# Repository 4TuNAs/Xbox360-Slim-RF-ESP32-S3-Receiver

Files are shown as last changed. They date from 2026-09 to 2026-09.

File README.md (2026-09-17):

# Xbox 360 Slim RF Board + ESP32-S3 SuperMini USB Receiver

A DIY Xbox 360 wireless controller receiver built around the **original Xbox 360 Slim RF board** and an **ESP32-S3 SuperMini**.

The ESP32 initializes the Microsoft RF board and handles its DATA, CLOCK, and SYNC/BTN control lines. USB data is connected to the RF board, while the ESP32-S3 is powered from USB +5 V and supplies 3.3 V to the RF board.

## Finished build

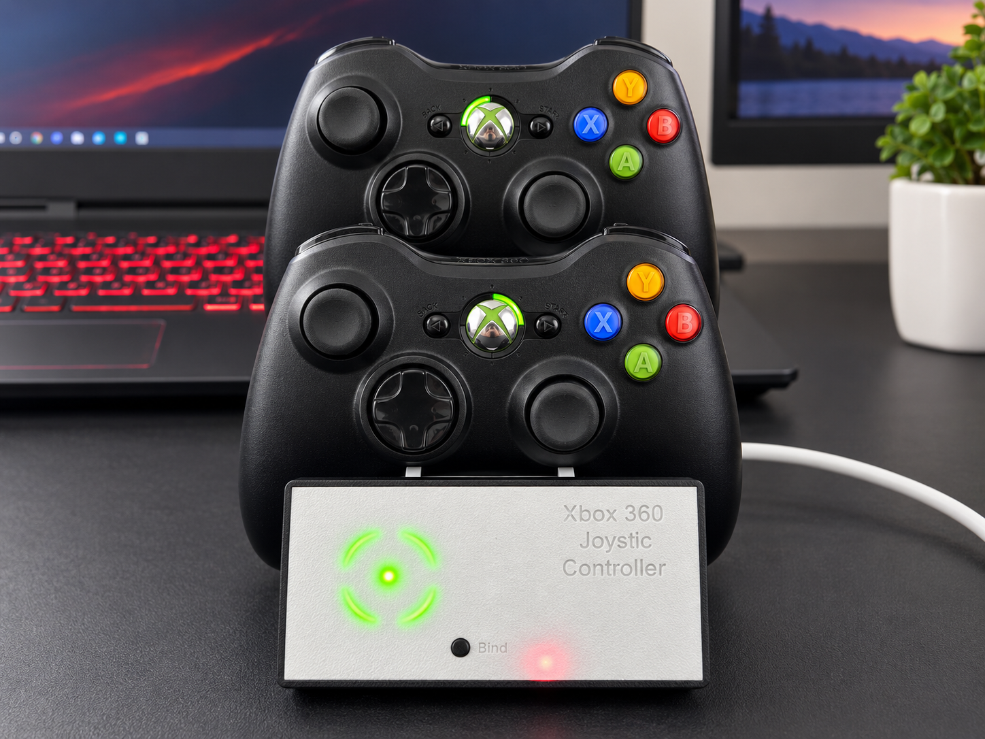
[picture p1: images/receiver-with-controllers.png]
Receiver with controllers


## Features

- Original Xbox 360 Slim RF board
- ESP32-S3 SuperMini controller
- Support for original Xbox 360 wireless controllers
- Original RF board pairing / Sync button support
- USB connection to Windows
- Standard Microsoft **Xbox 360 Wireless Receiver for Windows** driver
- Custom 3D-printable enclosure

## Hardware

- Xbox 360 Slim RF board
- ESP32-S3 SuperMini
- USB cable
- **2 × 10 kΩ resistors**
- Hook-up wire
- Soldering equipment
- Optional 3D-printed enclosure

The enclosure model is included in [`hardware/xbox360-slim-rf-receiver-enclosure.3mf`](hardware/xbox360-slim-rf-receiver-enclosure.3mf).

### Internal assembly

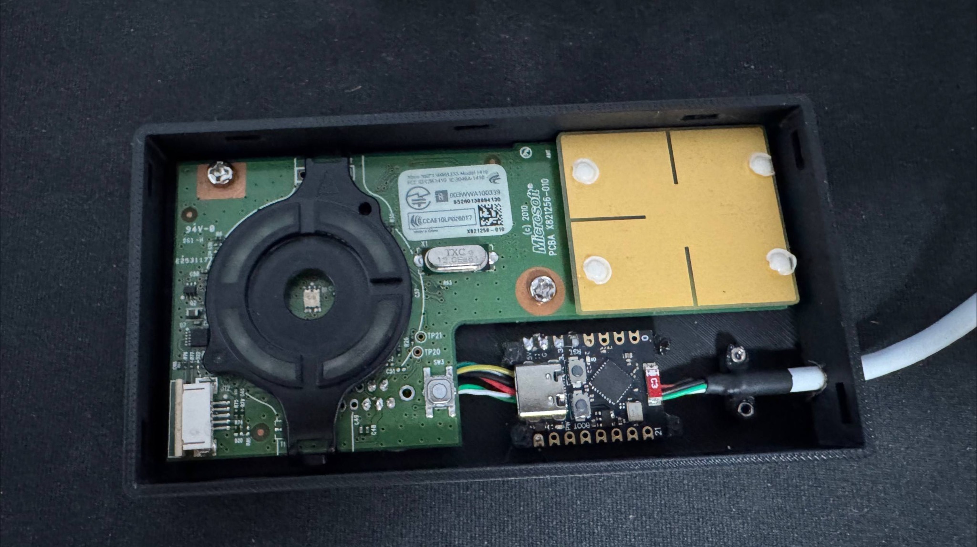
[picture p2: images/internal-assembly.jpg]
Internal assembly


## Wiring

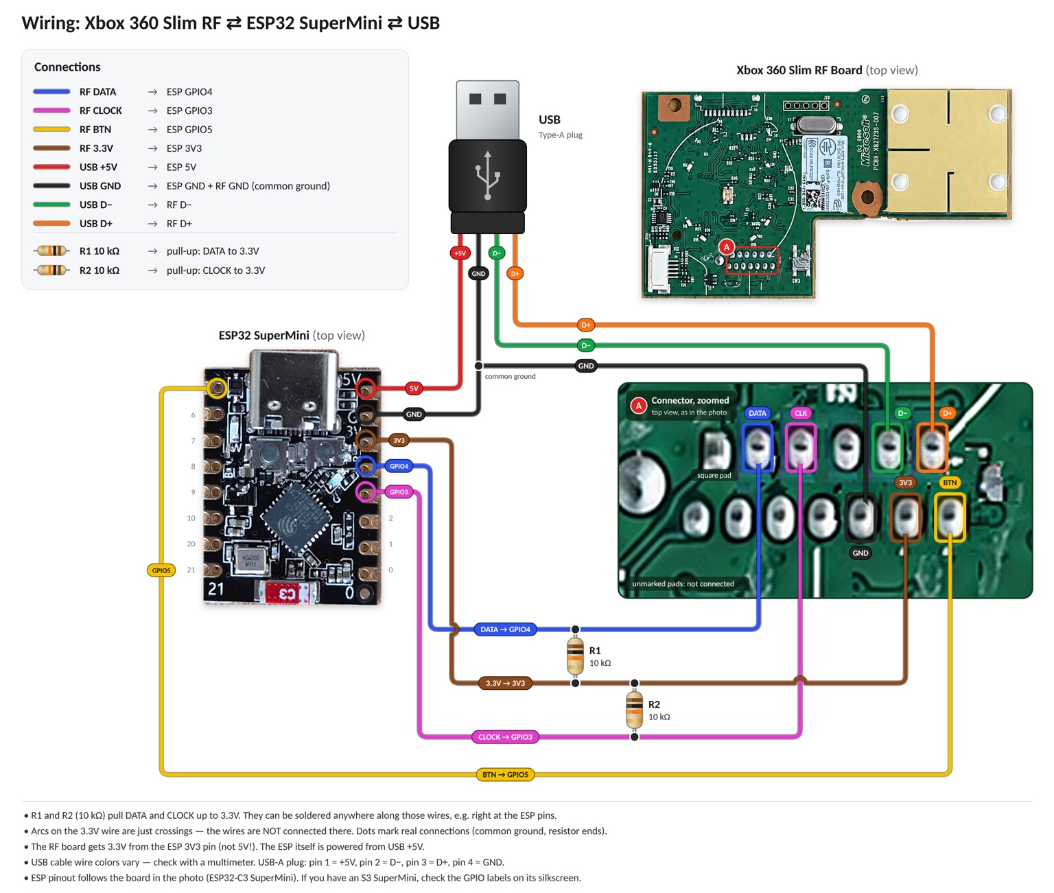
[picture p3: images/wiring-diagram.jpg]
Wiring diagram


> [!IMPORTANT]
> **Two external 10 kΩ pull-up resistors are mandatory.** DATA and CLOCK must each be pulled up to **3.3 V**. In this build the receiver does not work correctly without these resistors; the ESP32 internal pull-ups alone are not sufficient.

### RF board ↔ ESP32-S3 SuperMini

| RF board signal | ESP32-S3 SuperMini |
|---|---|
| DATA | GPIO4 |
| CLOCK | GPIO3 |
| BTN / SYNC | GPIO5 |
| 3.3 V | 3V3 |
| GND | GND |

### USB

| USB signal | Connection |
|---|---|
| +5 V / VBUS | ESP32-S3 5V |
| GND | ESP32-S3 GND + RF board GND (common ground) |
| D− | RF board USB D− |
| D+ | RF board USB D+ |

The RF board is powered from the ESP32-S3 **3V3** pin, **not directly from USB 5 V**.

USB cable colors are not guaranteed. Verify the conductors with a multimeter before soldering. A typical USB-A cable uses pin 1 = +5 V, pin 2 = D−, pin 3 = D+, pin 4 = GND.

### Mandatory pull-up resistors

Install two external **10 kΩ** pull-up resistors:

```text
3.3 V
  │
  ├── 10 kΩ ── DATA  ── GPIO4
  │
  └── 10 kΩ ── CLOCK ── GPIO3
```

- **R1: 10 kΩ** from DATA to 3.3 V
- **R2: 10 kΩ** from CLOCK to 3.3 V

They can be soldered anywhere along the DATA and CLOCK lines; placing them near the ESP32 pins is convenient.

> [!WARNING]
> Do not omit R1 and R2. Without the external pull-ups, communication with the RF board does not work correctly in this build.

### ESP32 pin assignment

The firmware uses:

```cpp
static constexpr uint8_t RF_CLOCK_PIN = 3;
static constexpr uint8_t RF_DATA_PIN  = 4;
static constexpr uint8_t SYNC_PIN     = 5;
```

So:

```text
GPIO3 -> RF CLOCK
GPIO4 -> RF DATA
GPIO5 -> RF BTN / SYNC
```

## Firmware

The firmware is in [`firmware/xbox360_rf_receiver.ino`](firmware/xbox360_rf_receiver.ino).

The RF board is initialized with the following command sequences:

```cpp
static const uint8_t START_COMMAND[10] = {
  0, 0, 0, 0, 0, 1, 0, 0, 1, 0
};

static const uint8_t POWER_COMMAND[10] = {
  0, 0, 1, 0, 0, 0, 0, 1, 0, 1
};

static const uint8_t SYNC_COMMAND[11] = {
  0, 0, 0, 0, 0, 0, 0, 1, 0, 0, 1
};
```

### RF board communication

The Xbox 360 Slim RF board generates CLOCK. To send a command, the ESP32 pulls DATA low to start the transaction and then updates DATA in sync with the RF board clock.

For each bit:

1. Wait for CLOCK LOW.
2. Set DATA to the required bit value.
3. Wait for CLOCK HIGH.
4. Repeat for the next bit.

After the final bit, DATA is driven HIGH and then released.

## Pairing a controller

After power-up the firmware initializes the RF board automatically.

To start pairing:

1. Turn on the Xbox 360 wireless controller.
2. Start Sync mode on the receiver by pressing the RF board Sync button, or send `S` in the serial monitor.
3. Press the Sync button on the controller.
4. Wait for the controller to pair.

The corresponding green quadrant on the RF board should remain illuminated after pairing.

## Serial commands

Serial baud rate: **115200**.

| Command | Function |
|---|---|
| `S` / `s` | Start controller synchronization |
| `I` / `i` | Reinitialize the RF board |

## Troubleshooting

### RF board does not respond / CLOCK timeout

Check these first:

- R1: DATA → 10 kΩ → 3.3 V
- R2: CLOCK → 10 kΩ → 3.3 V
- GPIO4 → DATA
- GPIO3 → CLOCK
- GPIO5 → BTN / SYNC
- RF board powered from 3.3 V
- Common ground between USB, ESP32-S3, and RF board

The external pull-ups are mandatory for this build.

### Windows shows Unknown Device

This is expected before the Xbox 360 receiver driver is selected. See **Windows driver installation** below.

## Project files

```text
.
├── README.md
├── firmware/
│   └── xbox360_rf_receiver.ino
├── hardware/
│   └── xbox360-slim-rf-receiver-enclosure.3mf
└── images/
    ├── wiring-diagram.jpg
    ├── internal-assembly.jpg
    ├── receiver-with-controllers.png
    └── driver-installation.png
```

## Disclaimer

This is an unofficial hardware modification project. Xbox, Xbox 360, and Microsoft are trademarks of Microsoft Corporation. This project is not affiliated with or endorsed by Microsoft.

## Windows driver installation

Windows may initially detect the receiver as **Unknown device (Code 28)**. Install the standard Microsoft Xbox 360 receiver driver manually.

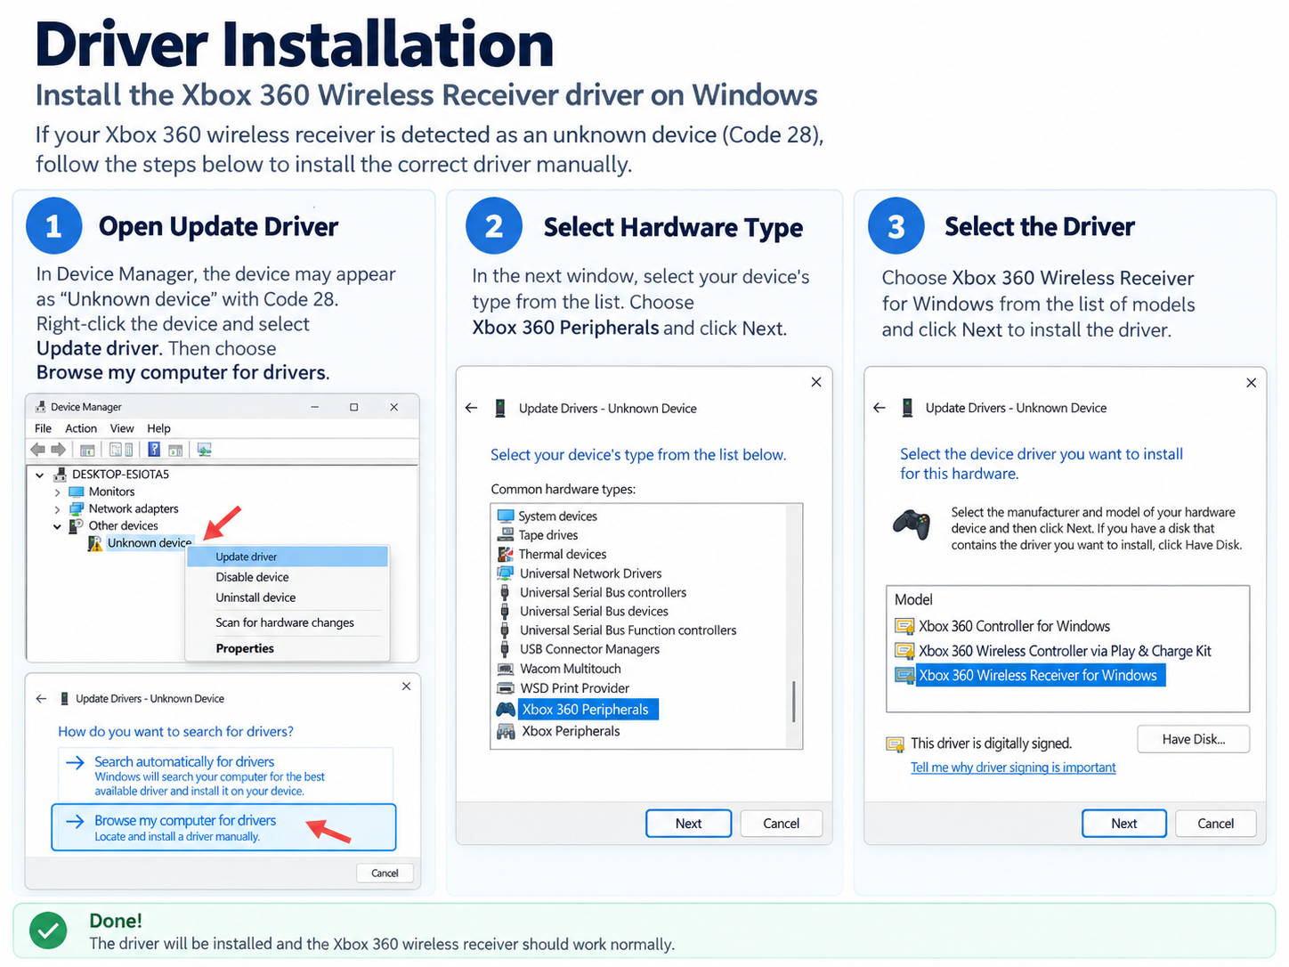
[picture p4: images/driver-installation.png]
Driver installation


1. Open **Device Manager**.
2. Right-click the unknown device and choose **Update driver**.
3. Select **Browse my computer for drivers**.
4. Select **Let me pick from a list of available drivers on my computer**.
5. Choose **Xbox 360 Peripherals**.
6. Select **Xbox 360 Wireless Receiver for Windows**.
7. Confirm the installation.

After installation, Windows should treat the device as an Xbox 360 wireless receiver.

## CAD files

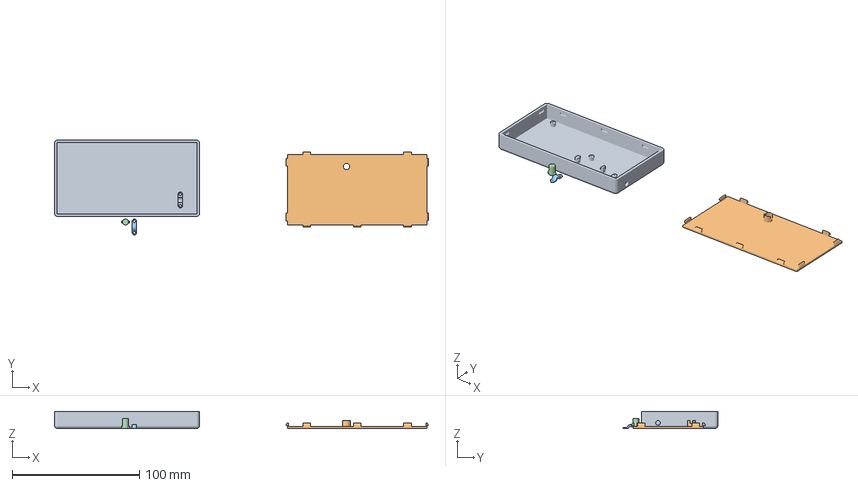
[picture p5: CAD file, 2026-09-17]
hardware/xbox360-slim-rf-receiver-enclosure.3mf
293.8 x 74.5 x 13.5 mm

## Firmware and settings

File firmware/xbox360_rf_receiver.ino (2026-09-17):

#include <Arduino.h>

static constexpr uint8_t RF_CLOCK_PIN = 3;
static constexpr uint8_t RF_DATA_PIN  = 4;
static constexpr uint8_t SYNC_PIN     = 5;

static constexpr uint32_t CLOCK_TIMEOUT_US = 200000;

static const uint8_t START_COMMAND[10] = {
  0, 0, 0, 0, 0, 1, 0, 0, 1, 0
};

static const uint8_t POWER_COMMAND[10] = {
  0, 0, 1, 0, 0, 0, 0, 1, 0, 1
};

static const uint8_t SYNC_COMMAND[11] = {
  0, 0, 0, 0, 0, 0, 0, 1, 0, 0, 1
};

bool waitClockLevel(uint8_t requiredLevel)
{
  uint32_t started = micros();

  while (digitalRead(RF_CLOCK_PIN) != requiredLevel) {
    if ((uint32_t)(micros() - started) > CLOCK_TIMEOUT_US) {
      return false;
    }
    delayMicroseconds(2);
  }

  return true;
}

void releaseDataLine()
{
  // Release DATA and keep the ESP32 internal pull-up enabled.
  // External 10 kOhm pull-ups on DATA and CLOCK are still required.
  pinMode(RF_DATA_PIN, INPUT_PULLUP);
}

bool sendCommand(const uint8_t *bits, size_t count)
{
  Serial.printf("Sending %u bits...\n", (unsigned)count);

  /*
   * Pulling DATA low tells the RF board that a command is starting.
   * The RF board should then begin generating CLOCK.
   */
  pinMode(RF_DATA_PIN, OUTPUT);
  digitalWrite(RF_DATA_PIN, LOW);

  delayMicroseconds(20);

  for (size_t i = 0; i < count; i++) {
    // Wait for CLOCK to go LOW.
    if (!waitClockLevel(LOW)) {
      releaseDataLine();
      Serial.printf("Error: no CLOCK falling edge, bit %u\n", (unsigned)i);
      return false;
    }

    delayMicroseconds(1000);
    digitalWrite(RF_DATA_PIN, bits[i] ? HIGH : LOW);

    // Wait for CLOCK to go HIGH.
    if (!waitClockLevel(HIGH)) {
      releaseDataLine();
      Serial.printf("Error: no CLOCK rising edge, bit %u\n", (unsigned)i);
      return false;
    }
  }

  /*
   * On the Slim RF board, DATA must be driven HIGH immediately after
   * the last bit and then released.
   */
  digitalWrite(RF_DATA_PIN, HIGH);
  delayMicroseconds(10);
  releaseDataLine();

  Serial.println("Command sent");
  return true;
}

bool initializeRf()
{
  Serial.println("Initializing RF board...");

  if (!sendCommand(START_COMMAND, 10)) {
    Serial.println("START_COMMAND failed");
    return false;
  }

  delay(50);

  if (!sendCommand(POWER_COMMAND, 10)) {
    Serial.println("POWER_COMMAND failed");
    return false;
  }

  delay(50);
  Serial.println("RF board initialized");
  return true;
}

void startSync()
{
  Serial.println("Sending SYNC command...");

  if (sendCommand(SYNC_COMMAND, 11)) {
    Serial.println("Turn on the controller and press its Sync button");
  } else {
    Serial.println("SYNC command failed");
  }
}

void setup()
{
  Serial.begin(115200);
  delay(1000);

  pinMode(RF_CLOCK_PIN, INPUT_PULLUP);
  pinMode(RF_DATA_PIN, INPUT_PULLUP);
  pinMode(SYNC_PIN, INPUT_PULLUP);

  Serial.println();
  Serial.println("Xbox 360 Slim RF + ESP32-S3");
  Serial.printf("DATA idle level: %d\n", digitalRead(RF_DATA_PIN));
  Serial.printf("CLOCK idle level: %d\n", digitalRead(RF_CLOCK_PIN));

  delay(1000);
  initializeRf();

  Serial.println("Press BOOT or send S to start Sync");
}

void loop()
{
  static bool previousButton = HIGH;
  bool button = digitalRead(SYNC_PIN);

  if (previousButton == HIGH && button == LOW) {
    delay(30);

    if (digitalRead(SYNC_PIN) == LOW) {
      startSync();

      while (digitalRead(SYNC_PIN) == LOW) {
        delay(10);
      }
    }
  }

  previousButton = button;

  while (Serial.available()) {
    char command = Serial.read();

    if (command == 's' || command == 'S') {
      startSync();
    }

    if (command == 'i' || command == 'I') {
      initializeRf();
    }
  }

  delay(5);
}

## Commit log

2026-09-17 Add ESP32-S3 RF receiver firmware
2026-09-17 Organize images and hardware assets
    [Xbox 360 Joystic Controller.3mf]
2026-09-17 Use descriptive asset filenames
    [xbox360-slim-rf-receiver-enclosure.3mf]
2026-09-17 Move Windows driver installation to end of README
2026-09-17 Improve README flow and place wiring diagram in Wiring section
2026-09-17 Move pull-up resistor notice into Wiring section
